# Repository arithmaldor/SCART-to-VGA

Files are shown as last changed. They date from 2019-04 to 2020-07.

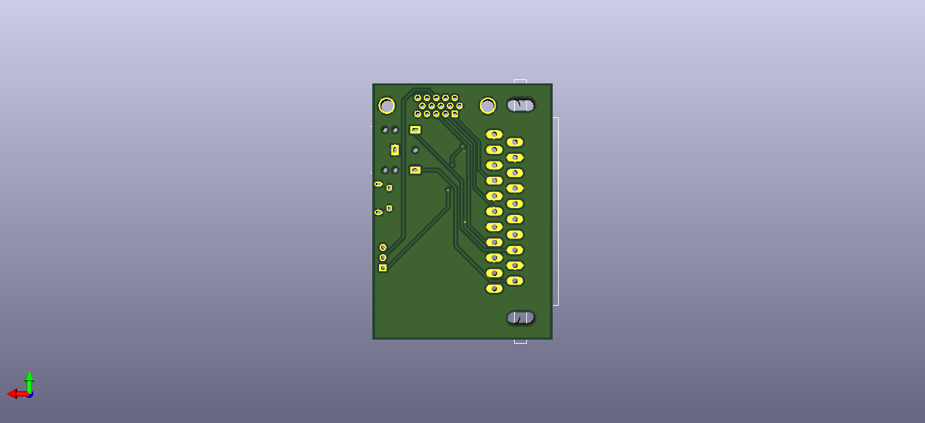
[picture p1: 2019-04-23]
Renders/1.0/SCART to VGA Bottom.png

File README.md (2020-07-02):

# SCART to VGA
Adapt SCART to VGA (RGBS) with optional sync stripper. You can either include all the parts and select on and off with the switch, or leave the sync stripper circuit off entirely and just connect the center leg of the switch with the leg nearest the "Bypass" text.

# License
Licensed under CERN OHL 1.2.

# Thanks
Thanks to Beyond Pixels (@ChristianBruyer) for the request/suggestion.

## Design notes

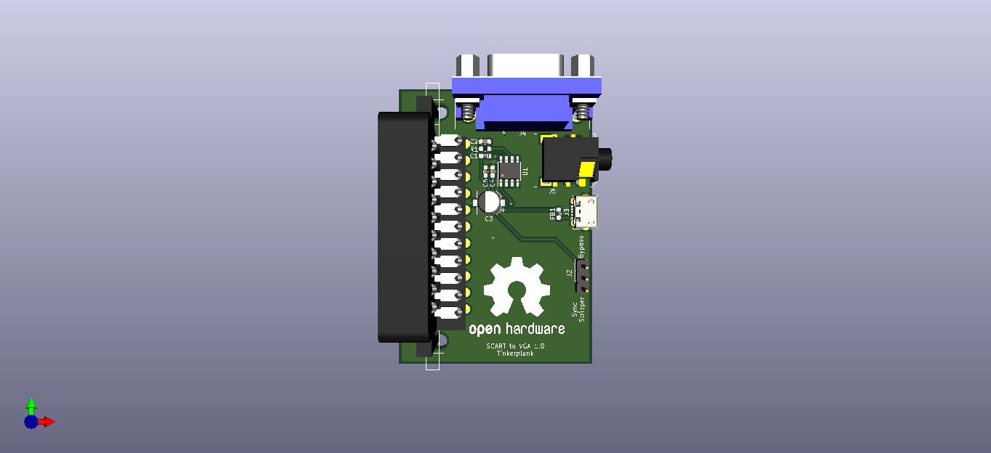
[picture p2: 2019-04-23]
Renders/1.0/SCART to VGA 3D Top.png

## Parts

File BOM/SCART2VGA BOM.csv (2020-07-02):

Qty | Ref(s) | Value | Footprint | Description | Note | Digikey | Arrow | LCSC | Other
1 | C5 | 10nF | 0603 | Ceramic 50V |  | https://www.digikey.com/product-detail/en/samsung-electro-mechanics/CL10B103KB8NCNC/1276-1921-1-ND/3890007 | https://www.arrow.com/en/products/cc0603krx7r9bb103/yageo | https://lcsc.com/product-detail/Others_Samsung-Electro-Mechanics_CL10B103KB8NFNC_Samsung-Electro-Mechanics-CL10B103KB8NFNC_C307477.html
3 | C1, C2, C4 | 100nF | 0603 | Ceramic 50V |  | https://www.digikey.com/product-detail/en/CL10F104ZO8NNNC/1276-1258-1-ND/3889344/ | https://www.arrow.com/en/products/cl10f104zo8nnnc/samsung-electro-mechanics | https://lcsc.com/product-detail/Multilayer-Ceramic-Capacitors-MLCC-SMD-SMT_100nF-104-10-50V_C14663.html
1 | C3 | 10uF | 4x5.4 | Elec. 25V |  | https://www.digikey.com/product-detail/en/panasonic-electronic-components/EEE-FK1E100R/PCE3795CT-ND/766171 | https://www.arrow.com/en/products/eeefk1e100r/panasonic | https://lcsc.com/product-detail/Others_PANASONIC-EEE1EA100WAR_C336730.html
1 | R1 | 680K | 0603 | 1% |  | https://www.digikey.com/product-detail/en/vishay-beyschlag/MCT06030C6803FP500/749-1673-1-ND/7347981 | https://www.arrow.com/en/products/mct06030c6803fp500/vishay
1 | FB1 | 220R | 0603 | Ferrite Bead |  | https://www.digikey.com/product-detail/en/tdk-corporation/MPZ1608S221ATA00/445-1565-1-ND/571895 | https://www.arrow.com/en/products/mpz1608s221ata00/tdk | https://lcsc.com/product-detail/Ferrite-Beads-And-Chips_TDK_MPZ1608S221ATA00_220R-25-at100MHz_C76815.html
1 | U1 | LM1881 | SOIC-8 |  |  | https://www.digikey.com/product-detail/en/texas-instruments/LM1881MX-NOPB/296-47437-1-ND/2139048 | https://www.arrow.com/en/products/lm1881mxnopb/texas-instruments | https://lcsc.com/product-detail/Interface-Specialized_HGSEMI-LM1881M-TR_C518922.html
1 | J1 | SCART | Right Angle |  |  |  |  |  | https://console5.com/store/female-scart-jp21-through-hole-pcb-mount-21-pin-connector-right-angle.html
1 | J3 | microUSB | Right Angle | Molex Style |  | https://www.digikey.com/product-detail/en/molex/1050170001/WM1399CT-ND/2350885 | https://www.arrow.com/en/products/1050170001/molex | https://lcsc.com/product-detail/USB-Connectors_Jing-Extension-of-the-Electronic-Co-LCSC-MICRO-USB-5S-B-Type-horns-High-temperature_C10418.html
1 | J4 | VGA | Right Angle | Female |  | https://www.digikey.com/product-detail/en/amphenol-icc-fci/ICD15S13E4GX00LF/609-5181-ND/1536501 | https://www.arrow.com/en/products/icd15s13e4gx00lf/amphenol-fci | https://lcsc.com/product-detail/D-Sub-Connectors_BOOMELE-Boom-Precision-Elec-VGA-002_C138387.html
1 | J5 | 3.5mm | Right Angle | Headphone | SJ1-3523NG | https://www.digikey.com/products/en?keywords=SJ1-3523NG | https://www.arrow.com/en/products/sj1-3523ng/cui-inc | https://lcsc.com/product-detail/Audio-Video-Connectors_BOOMELE-Boom-Precision-Elec-PJ-307C_C16684.html
1 | SW1 | DPDT | THT RA |  |  | https://www.digikey.com/product-detail/en/c-k/JS202011AQN/401-2000-ND/1640096 | https://www.arrow.com/en/products/js202011aqn/ck | https://lcsc.com/product-detail/Toggle-Switches_C-K_JS202011AQN_C-K-JS202011AQN_C221662.html

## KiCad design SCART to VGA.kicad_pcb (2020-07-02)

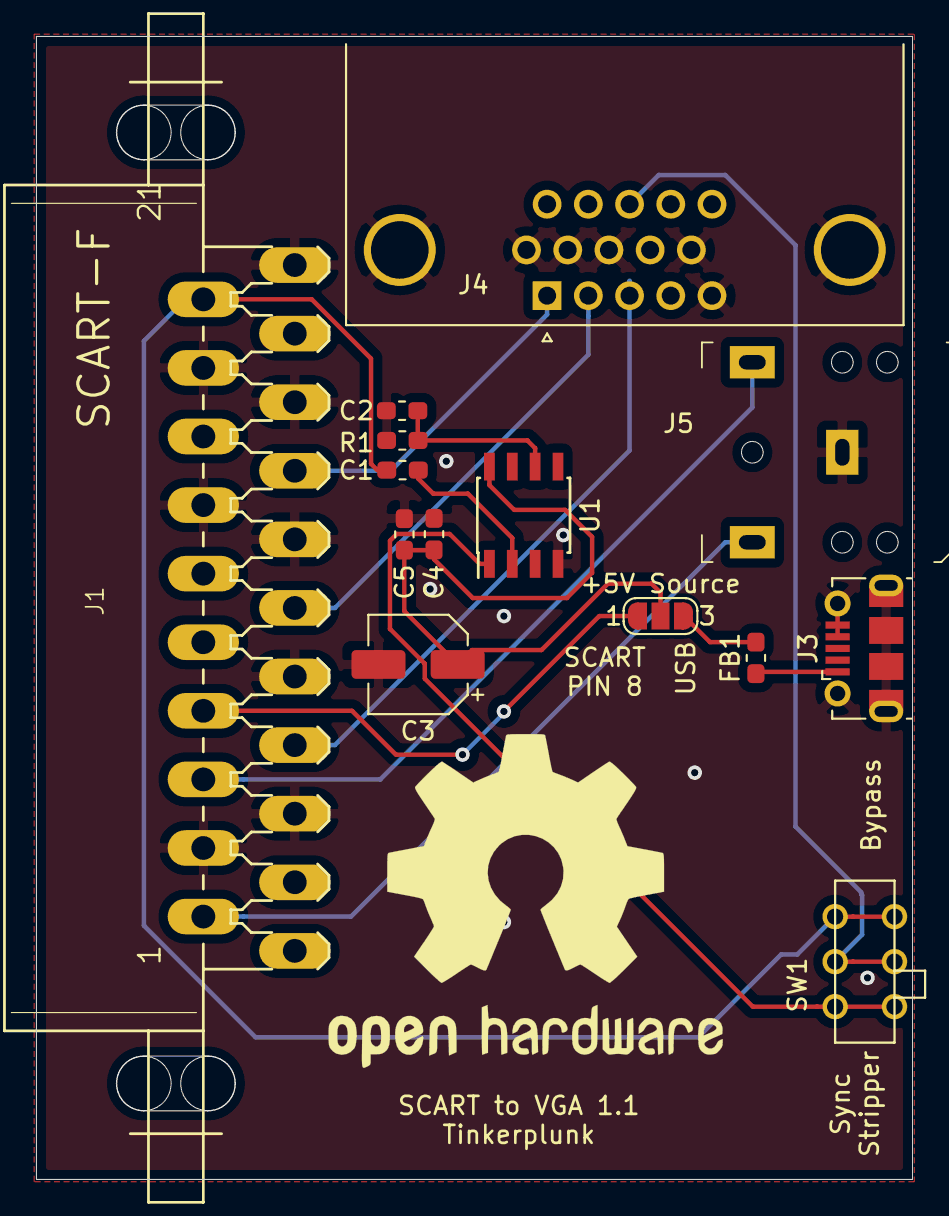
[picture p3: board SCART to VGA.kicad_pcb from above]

Board: 2 copper layers, 48.7 x 63.5 mm, 14 parts (0 on the bottom side), 14 nets.

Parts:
+5V Source: SolderJumper_3_Bridged12; SolderJumper-3_P1.3mm_Open_RoundedPad1.0x1.5mm_NumberLabels
C1, C2, C4: 100nF; C_0603_1608Metric_Pad1.05x0.95mm_HandSolder
C3: 10uF; CP_Elec_5x5.3
C5: 10nF; C_0603_1608Metric_Pad1.05x0.95mm_HandSolder
FB1: 220OHM; L_0603_1608Metric_Pad1.05x0.95mm_HandSolder
J1: SCART-F
J3: USB_B_Micro; USB_Micro-B_Molex-105017-0001
J4: DB15_Female_HighDensity; VGA
J5: AudioJack3; Headphone_Jack_3.5mm_SJ1-3523N
R1: 680K; R_0603_1608Metric_Pad1.05x0.95mm_HandSolder
SW1: Conn_01x03_Male; DPDT
U1: LM1881; SOIC-8_3.9x4.9mm_P1.27mm

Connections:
BLUE: J1.7, J4.3
GND: C2.2, C3.2, C4.1, C5.1, J1.4, J1.5, J1.9, J1.13, J1.14, J1.17, J1.18, J1.21, J3.4, J3.5, J3.6, J4.0, J4.5, J4.6, J4.7, J4.8, J4.10, J5.S, R1.2, U1.4
GREEN: J1.11, J4.2
LEFT: J1.6, J5.T
unnamed: C1.1, U1.2
unnamed: C2.1, R1.1, U1.6
unnamed: +5V Source.2, C3.1, C4.2, C5.2, U1.8
unnamed: FB1.1, J3.1
unnamed: +5V Source.1, J1.8
unnamed: SW1.1, SW1.4, U1.1
RED: J1.15, J4.1
RIGHT: J1.2, J5.R
SYNC_IN: C1.2, J1.20, SW1.3, SW1.6
SYNC_OUT: J4.13, SW1.2, SW1.5

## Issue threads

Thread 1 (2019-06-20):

Audio Ouput Ground Not Connected

dwardman, 2019-06-20:
Hi, I'm new to this but it looks like your audio ground pin is not connected?

dwardman, 2019-06-24:
Scratch that, I needed to view with KiCad.

arithmaldor, 2019-06-25:
I need to update the renders

arithmaldor, 2019-06-25:
Renders updated, you can see the ground is connected.

Closed 2019-06-25.

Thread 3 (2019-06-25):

Wrong part for C3 on the BOM

arithmaldor, 2019-06-25:
And change the BOM to a CSV while you're at it.

Closed 2019-07-31.

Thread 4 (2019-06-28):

VGA Footprint

eltair, 2019-06-28:
The VGA connector in the BOM has 2.54mm between rows, but the footprint uses 1.98mm. I was able to bend the pins in to get them soldered, but it would be nice to get the footprint fixed as I could not find any parts across multiple site that use 1.98mm.

Closed 2020-07-02.

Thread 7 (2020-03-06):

+5v should be powered by the SCART Cable

amoore2600, 2020-03-06:
There's is no need to power the LM1881 from USB. Every SCART connection should supply +5v. (All game consoles have +5v)

A second set of jumpers could also be added to switch between SCART +5v and USB +5v Power. Looks like there lots of room on the PCB for it.

There might be a 180 Ohm resistor needed between the SCART +5V and the LM1881.

here is my hack job of this in action (no 180 ohm resistor).

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

mmmonkeygrimes, 2020-06-23:
How does the fact that some PAL Scart leads output (correctly)  up-to 12v on Scart Pin 8 affect this?

http://members.optusnet.com.au/eviltim/gamescart/gamescart.htm#jaguar
http://members.optusnet.com.au/eviltim/gamescart/gamescart.htm#xbox
http://members.optusnet.com.au/eviltim/gamescart/gamescart.htm#snes (PAL model)
http://members.optusnet.com.au/eviltim/gamescart/gamescart.htm#gamecube (PAL model)
http://members.optusnet.com.au/eviltim/gamescart/gamescart.htm#wii
http://members.optusnet.com.au/eviltim/gamescart/gamescart.htm#dcast
https://nfggames.com/forum2/index.php?topic=4236.0

It looks like the LM1881 is okay receiving between 5 and 12v, but I don't  understand if it affects the output at all?

Closed 2020-07-02.

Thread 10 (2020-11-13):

RGBHV

finos2, 2020-11-13:
hello i have a scart tv , i want to connect to it a vga source from my emulation pc , from my understanding this is not possibe with that adapter ? but what Exactly makes it imposible ? Sync ? horizontal or vertical refresh rate ?  i know this does not realy classify as an issue but info on this subject is too information is sparse and hard to understand

arithmaldor, 2020-11-13:
For that you would be going VGA to SCART, if you were able to send a 15khz signal from your PC you could combine the H and V syncs using a sync combining circuit, I recommend https://www.retrorgb.com/building-a-passive-sync-combiner.html.

Closed 2020-11-13.

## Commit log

2019-04-23 renamed gerber file
    [SCART to VGA.kicad_pcb]
2019-04-23 Trace movement
    slightly moved some traces farther away from the SCART through holes
    [SCART to VGA.kicad_pcb]
2020-07-02 Closed all open issues
    1. added jumper for voltage source
    2. changed pin headers to 2 row dpdt switch
    3. Changed VGA to correct footprint
    4. Fixed placement of headphone jack
    5. Converted BOM to csv
    6. updated license file.
    [SCART to VGA-B_Cu.gbl, SCART to VGA-B_Mask.gbs, SCART to VGA-B_Paste.gbp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]
